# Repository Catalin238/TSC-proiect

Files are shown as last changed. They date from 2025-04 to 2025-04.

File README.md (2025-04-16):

# TSC-proiect

1. Diagrama Bloc



2. Bill of materials

| Piece Name | Quantity | Link |
|---|---|---|
| ESP32 | 1 | https://www.snapeda.com/parts/ESP32-C6-WROOM-1-N8/Espressif%20Systems/view-part/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 |
| BME680 | 1 | https://www.snapeda.com/parts/BME680/Bosch%20Sensortec/view-part/?ref=search&t=bme680 |
| DS3231SN | 1 | https://www.snapeda.com/parts/DS3231SN%23/Analog%20Devices/view-part/?ref=search&t=DS3231SN%23 |
| W25Q512JVEIQ | 1 | https://www.snapeda.com/parts/W25Q512JVEIQ/Winbond%20Electronics/view-part/?ref=search&t=W25Q512JVEIQ |
| MCP73831 | 1 | https://componentsearchengine.com/part-view/MCP73831T-2ACI%2FOT/Microchip |
| MOSFET | 1 | https://componentsearchengine.com/part-view/DMG2305UX-7/Diodes%20Incorporated |
| SAMACSYS_PARTS_USB4110-GF-A | 1 | https://www.snapeda.com/parts/USB4110-GF-A./Global%20Connector%20Technology/view-part/ |
| USBLC6-2SC6Y | 1 | https://www.snapeda.com/parts/USBLC6-2SC6Y/STMicroelectronics/view-part/?ref=dk&t=USBLC6-2SC6Y&con_ref=None |
| BD5229G-TR | 1 | https://www.snapeda.com/parts/BD5229G-TR/Rohm/view-part/?ref=search&t=BD5229G-TR |
| QWIIC_CONNECTOR | 1 | https://www.snapeda.com/parts/PRT-14417/SparkFun/view-part/ |
| CPH3225A | 1 | https://www.snapeda.com/parts/CPH3225A/Seiko/view-part/ |
| BUTTON_CUSYOMV1 | 3 | https://www.snapeda.com/search/?q=EVQP7L01P&search-type=parts |
| ADAFRUIT_LEDCHIP-LED0603 | 1 | https://www.snapeda.com/parts/KP-1608SURCK/Kingbright/view-part/?ref=search&t=LED%200603 |
| C0402 | 1 | https://componentsearchengine.com/part-view/CC0402MRX5R5BB106/YAGEO |
| 112ATAARR03 | 1 | https://www.snapeda.com/parts/112A-TAAR-R03/Attend/view-part/ |
| 744043680 | 1 | https://eu.mouser.com/ProductDetail/Wurth-Elektronik/744043680?qs=PGXP4M47uW6VkZq%252BkzjrHA%3D%3D |
| R0402 | 1 | https://componentsearchengine.com/part-view/R0402%201%25%20100%20K%20(RC0402FR-07100KL)/YAGEO |
| SD0805S020S1R0 | 1 | https://componentsearchengine.com/part-view/SD0805S020S1R0/Kyocera%20AVX |
| VARISTOR | 1 | https://ro.mouser.com/ProductDetail/EPCOS-TDK/B72520T0350K062?qs=dEfas%2FXlABIszF52uu7vrg%3D%3D |
| SRJ | 1 | https://componentsearchengine.com/part-view/FH34SRJ-24S-0.5SH(99)/Hirose |
| MBR0530 | 1 | https://www.snapeda.com/parts/MBR0530/Onsemi/view-part/ |
| PGB1010603MR | 1 | https://www.snapeda.com/parts/PGB1010603MR/Littelfuse/view-part/ |
| RCL_CPOL-EU | 1 | https://grabcad.com/library/tantalum-smd-capacitor-type-b-3528-1 |
| SI1308EDL-T1-GE3 | 1 | https://www.snapeda.com/parts/SI1308EDL-T1-GE3/Vishay/view-part/ |
| XC6220A331MR-G | 1 | https://ro.mouser.com/ProductDetail/Torex-Semiconductor/XC6220A331MR-G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 |

3. Functionalitati Hardware

Structura si Functionalitati:

ESP32-C6-WROOM-1-N8
Functie: Procesor central al sistemului, gestioneaza protocoalele de comunicare (SPI, I2C, UART), achizitia datelor de la senzori si controlul dispozitivelor periferice.

Connector USB-C cu Protectie ESD
Functie: Ofera posibilitatea incarcarii prin port USB-C si implementeaza circuite de protectie impotriva descarcarilor electrostatice.

Controller de Incarcare (MCP73831)
Functie: Administreaza procesul de incarcare pentru acumulatorul Li-Po si regleaza parametrii curentului de incarcare.

Acumulator Li-Po
Functie: Furnizeaza energie autonoma, permitand functionarea dispozitivului independent de conexiunea USB.

Regulator de Tensiune LDO
Functie: Converteste si mentine o tensiune stabila de 3.3V pentru alimentarea microcontrolerului si a componentelor auxiliare.

Memorie Flash NOR Externa 64MB
Functie: Asigura spatiu de stocare aditional pentru date operationale si actualizari de firmware.

Modul RTC (DS3231SN)
Functie: Asigura cronometrarea precisa si mentinerea datei/orei curente.
Conectivitate: Protocol I2C, include functii de alarma si baterie de rezerva pentru mentinerea timpului.

Senzor de Mediu (BME688)
Functie: Colecteaza parametri ambientali precum temperatura, umiditatea, presiunea atmosferica si compusi organici volatili.
Conectivitate: Comunicare I2C, optimizat pentru consum redus in standby, cu capacitati avansate de detectare a gazelor.
Implementare: Utilizeaza interfata standardizata Qwiic / Stemma QT pentru conectare plug-and-play.

Circuit de Control pentru Afisaj E-Paper si Conector
Functie: Produce semnalele specifice pentru operarea afisajelor electroforetice si faciliteaza compatibilitatea cu diferite tipuri de ecrane.
Conectivitate: Protocol SPI, cu linii dedicate pentru control (Busy, Reset, DC, CS).

Card SD
Functie: Faciliteaza stocarea extinsa a datelor, fisierelor de configurare si inregistrarilor pe termen lung.
Conectivitate: Interfata SPI cu linie dedicata de selectie.

Supervisor de Tensiune si Butoane Reset/Boot
Functie: Supravegheaza nivelul tensiunii de alimentare si controleaza secventele de initializare si repornire ale ESP32-C6.

Interfete si Protocoale de Comunicare:

I2C: Implementat pentru comunicarea cu BME688 si DS3231SN.
SPI: Utilizat pentru accesarea memoriei Flash NOR, controlul afisajului E-Paper si operatiunile cu cardul SD.
UART: Disponibil pentru debugging si integrarea modulelor externe optionale.
Wi-Fi si Bluetooth LE: Functionalitati native ale ESP32-C6.

Analiza Consumului Energetic:

ESP32-C6:
Consum in regim activ: ~80-240 mA (variabil in functie de activitatea Wi-Fi/BT).
Consum in regim economic: sub 1 mA (in modul deep sleep).

BME688:
Consum caracteristic: ~2.1 µA in repaus, maxim ~3.1 mA in operare completa.

Memorie Flash NOR:
Consum la citire/scriere: 5-15 mA, in asteptare: sub 10 µA.

DS3231SN:
Consum constant: aproximativ 150 µA cu functia de backup activa.

Regulator LDO:
Randamentul energetic variaza in functie de diferenta dintre tensiunea de intrare si cea de iesire (3.3V) si de curentul total solicitat.

4. Pini ESP32-C6

| Pin ESP32-C6  | Componenta / Rol | Descriere |
|---|---|---|
| IO8 (SCK) | SPI Clock | Semnal de clock SPI |
| IO6 (MOSI) | SPI MOSI catre NOR Flash, E-Paper, SD Card | Transfer date catre periferice SPI |
| IO7 (MISO) | SPI MISO din NOR Flash, E-Paper, SD Card | Receptie date de la periferice SPI |
| IO9 (CS1) | Chip Select NOR Flash | Control dedicat pentru NOR Flash |
| IO11 (CS3) | Chip Select SD Card | Control dedicat pentru SD Card |
| IO10 (CS2) | Chip Select E-Paper Display | Control dedicat pentru Display |
| IO15 (SCL) | I2C SCL catre BME688 si DS3231SN | Semnal de clock I2C |
| IO14 (SDA) | I2C SDA catre BME688 si DS3231SN | Date pentru I2C |
| IO21 | Reset/Boot control | Butoane de reset si boot |
| IO16, IO17 | UART RX, TX (debug) | Debug serial si configurare |

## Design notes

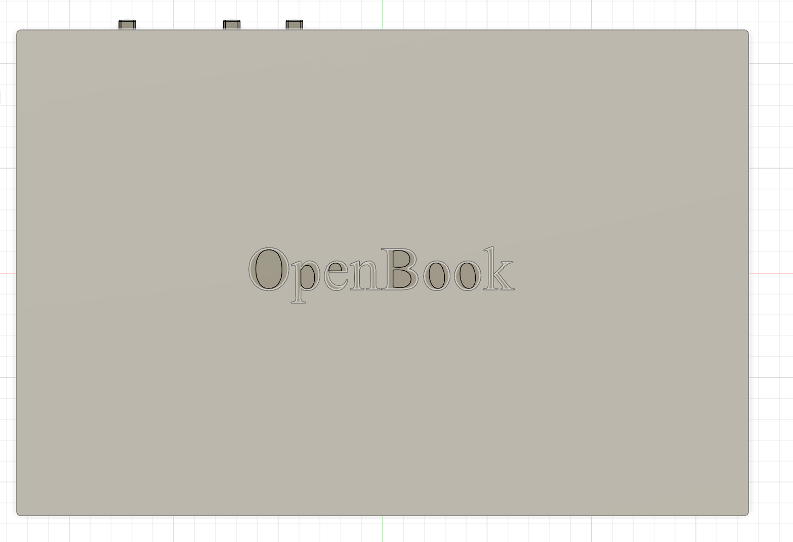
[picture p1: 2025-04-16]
Images/OpenBook Enclosure.png

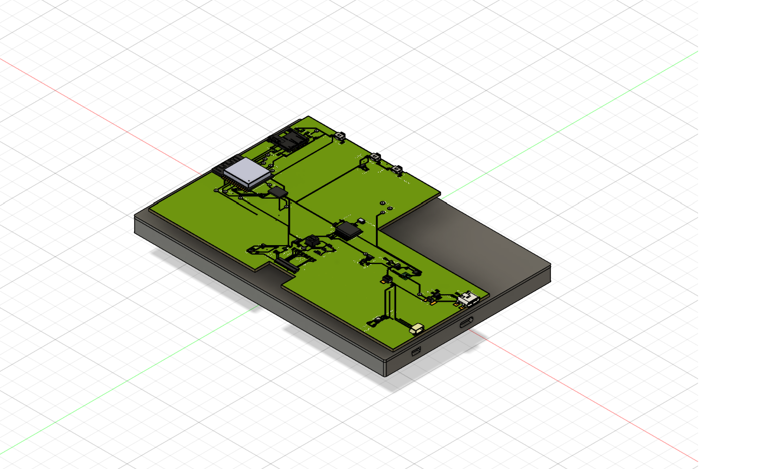
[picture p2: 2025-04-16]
Images/OpenBook.png

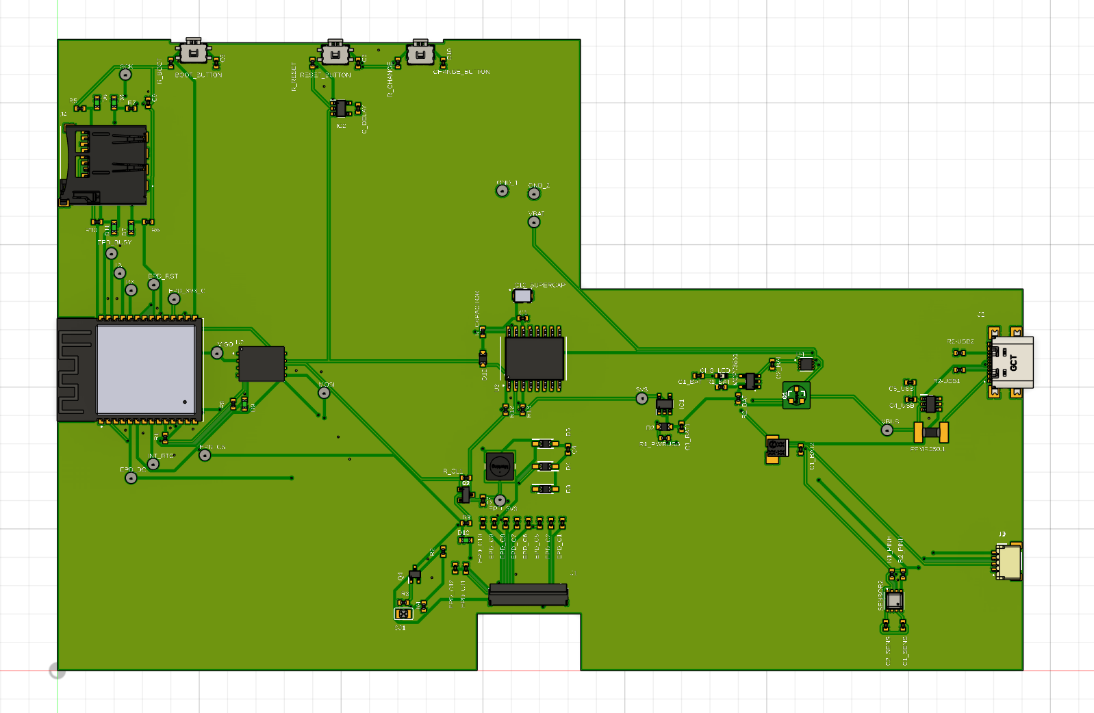
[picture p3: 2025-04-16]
Images/3d_board.png

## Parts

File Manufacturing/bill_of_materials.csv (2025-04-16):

Qty | Value | Device | Package | Parts | Description | ARROW_PART_NUMBER | ARROW_PRICE-STOCK | AVAILABILITY | BOOT_BUTTON | CENTROID_NOT_SPECIFIED | CHANGE_BUTTON | CHECK_PRICES | COPYRIGHT | DATASHEET | DESCRIPTION | DIGIKEY_DESCRIPTION | DIGIKEY_PART_NUMBER | DMG2305UX-7 | HEIGHT | LEAD_FREE | MANUFACTURER_NAME | MANUFACTURER_PART_NUMBER | MF | MFR_NAME | MOUSER_PART_NUMBER | MOUSER_PRICE-STOCK | MOUSER_TESTING_PART_NUMBER | MOUSER_TESTING_PRICE-STOCK | MP | MPN | PACKAGE | POPULARITY | PREFIX | PRICE | PROD_ID | PURCHASE-URL | RESET_BUTTON | ROHS | SNAPEDA_LINK | SPICEPREFIX | TEMPERATURE_RANGE_HIGH | TEMPERATURE_RANGE_LOW | VALUE
1 |  | SJ | SJ | SJ1 | SMD solder JUMPER |  |  |  |  |  |  |  |  |  |  |  |  |  |  |  |  |  |  |  |  |  |  |  |  |  |  | 3
1 | 0.1uF/50V | EAGLE-LTSPICE_C | EAGLE-LTSPICE_C0402 | EPD_C5 | CAPACITOR, European symbol
1 | 0.47 | ESP32_WROVER_EAGLE-LTSPICE_R | ESP32_WROVER_EAGLE-LTSPICE_R0402 | R2 | RESISTOR, European symbol
1 | 100K | ESP32_WROVER_EAGLE-LTSPICE_R | ESP32_WROVER_EAGLE-LTSPICE_R0402 | R1_PWRUSB | RESISTOR, European symbol
8 | 100nF | EAGLE-LTSPICE_C | EAGLE-LTSPICE_C0402 | C1, C1_SENS, C2_SENS, C4_USB, C6, C9, C10, C_DELAY | CAPACITOR, European symbol
1 | 100uF TANT | RCL_CPOL-EUCT3528 | RCL_CT3528 | C3 | POLARIZED CAPACITOR, European symbol |  |  |  |  |  |  |  |  |  |  |  |  |  |  |  |  |  |  |  |  |  |  |  |  |  |  | 0 |  |  |  |  |  |  |  | C
16 | 10K | ESP32_WROVER_EAGLE-LTSPICE_R | ESP32_WROVER_EAGLE-LTSPICE_R0402 | R1, R1_PINH, R2_PINH, R3, R5, R6, R7, R8, R9, R10, R12, R13, R_BOOT, R_CHANGE, R_CL1, R_RESET | RESISTOR, European symbol
1 | 10uF | EAGLE-LTSPICE_C | EAGLE-LTSPICE_C0402 | C7 | CAPACITOR, European symbol
1 | 112A-TAAR-R03_ATTEND | 112A-TAAR-R03_ATTEND | 112ATAARR03ATTEND | J4 | Micro SD Card Socket, Push-Push Type, Top Mount, SMT, H=1.83mm, 10u |  |  |  |  |  |  |  |  |  | Micro SD Card Socket | Push-Push Type | Top Mount | SMT | H=1.83mm | 10u |  |  |  | 1.9mm |  | ATTEND | 112A-TAAR-R03 ATTEND
1 | 15 | ESP32_WROVER_EAGLE-LTSPICE_R | ESP32_WROVER_EAGLE-LTSPICE_R0402 | R_CAPACITOR | RESISTOR, European symbol
1 | 1uF | EAGLE-LTSPICE_C | EAGLE-LTSPICE_C0402 | C5 | CAPACITOR, European symbol
9 | 1uF/50V | EAGLE-LTSPICE_C | EAGLE-LTSPICE_C0402 | EPD_C1, EPD_C2, EPD_C6, EPD_C7, EPD_C8, EPD_C9, EPD_C10, EPD_C11, EPD_C12 | CAPACITOR, European symbol
1 | 2.2 | ESP32_WROVER_EAGLE-LTSPICE_R | ESP32_WROVER_EAGLE-LTSPICE_R0402 | R4 | RESISTOR, European symbol
1 | 200 | ESP32_WROVER_EAGLE-LTSPICE_R | ESP32_WROVER_EAGLE-LTSPICE_R0402 | R1_BAT | RESISTOR, European symbol
2 | 20V/4.2A/52mO/1.4W | ESP32_WROVER_SPARKFUN-DISCRETESEMI_MOSFET_PCH | ESP32_WROVER_SPARKFUN-DISCRETESEMI_SOT23-3 | Q1, Q2 | P-channel MOSFETs
1 | 2K | ESP32_WROVER_EAGLE-LTSPICE_R | ESP32_WROVER_EAGLE-LTSPICE_R0402 | R2_BAT | RESISTOR, European symbol
5 | 4.7uF | EAGLE-LTSPICE_C | EAGLE-LTSPICE_C0402 | C1_BAT, C1_BAT1, C1_BAT2, C2_BAT, C5_USB | CAPACITOR, European symbol
1 | 4.7uF/25V | EAGLE-LTSPICE_C | EAGLE-LTSPICE_C0402 | C4 | CAPACITOR, European symbol
2 | 5k1 | ESP32_WROVER_EAGLE-LTSPICE_R | ESP32_WROVER_EAGLE-LTSPICE_R0402 | R2-USB1, R2-USB2 | RESISTOR, European symbol
1 | 68uH | 744043680IND_4828-WE-TPC_WRE | IND_4828-WE-TPC_WRE | L1 |  |  |  |  |  |  |  |  | Copyright (C) 2024 Ultra Librarian. All rights reserved. |  |  |  |  |  |  |  |  | 744043680 |  | Wurth Electronics
1 | BD5229G-TR | BD5229G-TR | SOT95P280X125-5N | IC2 | Voltage Detector with Adjustable Delay Time: CMOS processes are utilized to develop high precision, low current consumption CMOS reset ICs that allow arbitrary setting of the delay time. The extensive lineup includes both Nch Open Drain and CMOS output types in a wide range of detection voltages (from 2.3V to 6.0V, in 0.1V steps), enabling selection of the ideal solution based on customer requirements. In addition, the entire series is of course both lead-free and RoHS-compliant. |  |  |  |  |  |  |  |  |  | Voltage Detector with Adjustable Delay Time: CMOS processes are utilized to develop high precision | low current consumption CMOS reset ICs that allow arbitrary setting of the delay time. The extensive lineup includes both Nch Open Drain and CMOS output types in a wide range of detection voltages (from 2.3V to 6.0V | in 0.1V steps) | enabling selection of the ideal solution based on customer requirements. In addition | the entire series is of course both lead-free and RoHS-compliant. |  |  |  | 1.25mm |  | ROHM Semiconductor | BD5229G-TR |  |  | 755-BD5229G-TR | https://www.mouser.co.uk/ProductDetail/ROHM-Semiconductor/BD5229G-TR?qs=4kLU8WoGk0vvnhrrYwdszw%3D%3D
1 | BME688 | ESP32_WROVER_BME680_BME680 | ESP32_WROVER_BME680_PSON80P300X300X100-8N | SENSOR2 | Integrated Environmental Unit |  |  | Unavailable |  |  |  |  |  |  | Integrated Environmental Unit |  |  |  |  |  |  |  | Bosch Sensortec |  |  |  |  |  | BME680 |  | LGA-8 Bosch Tools |  |  | None
3 | BUTTON_CUSYOMV1 | BUTTON_CUSYOMV1 | MYBUTTON | BOOT_BUTTON, CHANGE_BUTTON, RESET_BUTTON
1 | CPH3225A | CPH3225A | CAPCP3225X100N | C10_SUPERCAP | Cap 0.011F 3.3V 1210 Flat Check availability |  |  | Not in stock |  |  |  | https://www.snapeda.com/parts/CPH3225A/Seiko+Instruments/view-part/?ref=eda |  |  | 11 mF (EDLC) Supercapacitor 3.3 V 1210 (3225 Metric) - - |  |  |  |  |  |  |  | Seiko Instruments |  |  |  |  |  | CPH3225A |  | 1210 Seiko |  |  | None |  | https://www.snapeda.com/api/url_track_click_mouser/?unipart_id=562593&manufacturer=Seiko Instruments&part_name=CPH3225A&search_term=None |  |  | https://www.snapeda.com/parts/CPH3225A/Seiko+Instruments/view-part/?ref=snap
1 | DS3231SN# | DS3231SN# | SOIC127P1032X265-16N | U3 | Real Time Clock Serial 16-Pin SOIC W T/R Check availability |  |  | In Stock |  |  |  | https://www.snapeda.com/parts/DS3231SN%23/Analog+Devices/view-part/?ref=eda |  |  | Extremely Accurate I²C-Integrated RTC/TCXO/Crystal |  |  |  |  |  |  |  | Analog Devices |  |  |  |  |  | DS3231SN# |  | SOIC-16 Maxim |  |  | None |  | https://www.snapeda.com/api/url_track_click_mouser/?unipart_id=99048&manufacturer=Analog Devices&part_name=DS3231SN#&search_term=None |  |  | https://www.snapeda.com/parts/DS3231SN%23/Analog+Devices/view-part/?ref=snap
1 | ESP32-C6-WROOM-1-N8 | ESP32-C6-WROOM-1-N8 | XCVR_ESP32-C6-WROOM-1-N8 | U1 | Check availability |  |  | In Stock |  |  |  | https://www.snapeda.com/parts/ESP32-C6-WROOM-1-N8/Espressif+Systems/view-part/?ref=eda |  |  | Multiprotocol Modules ESP32-C6 module | Wi-Fi 6 in 2.4 GHz band | Bluetooth 5 | Zigbee 3.0 and Thread. ESP34-WROOM Compatible - ENGINEERING SAMPLE |  |  |  |  |  |  |  | Espressif Systems |  |  |  |  |  | ESP32-C6-WROOM-1-N8 |  | None |  |  | None |  |  |  |  | https://www.snapeda.com/parts/ESP32-C6-WROOM-1-N8/Espressif+Systems/view-part/?ref=snap
1 | ESP32C6_VARISTORCN1812 | ESP32C6_VARISTORCN1812 | ESP32C6_VARISTOR_CT/CN1812 | PFMF.050.1 | VARISTOR |  |  |  |  |  |  |  |  |  |  |  |  |  |  |  |  |  |  |  |  |  |  |  |  |  |  | 0
2 | ESP32_WROVER_AVX---SD0805S020S1R0_AVX_SD0805S020S1R0_0_0AVX_SD0805S020S1R0_0_0 | ESP32_WROVER_AVX---SD0805S020S1R0_AVX_SD0805S020S1R0_0_0AVX_SD0805S020S1R0_0_0 | ESP32_WROVER_AVX---SD0805S020S1R0_AVX_SD0805S020S1R0_0 | D2, D12 | Schottky Barrier Rectifier Diode |  |  |  |  | No |  |  |  | http://datasheets.avx.com/schottky.pdf |  | DIODE SCHOTTKY 20V 1A 0805 | 478-7800-1-ND |  |  | yes |  |  | AVX |  | 581-SD0805S020S1R0 |  |  |  |  |  | 0805 (2012 metric) |  | D |  |  |  |  | yes |  |  | +125°C | -55°C
1 | ESP32_WROVER_SPARKFUN-IC-POWER_MCP73831 | ESP32_WROVER_SPARKFUN-IC-POWER_MCP73831 | ESP32_WROVER_SPARKFUN-IC-POWER_SOT23-5 | MCP73831 | MCP73831T Li-Ion, Li-Pol Controller |  |  |  |  |  |  |  |  |  |  |  |  |  |  |  |  |  |  |  |  |  |  |  |  |  |  |  |  |  | IC-09995
1 | FH34SRJ-24S-0.5SH_99_ | FH34SRJ-24S-0.5SH_99_ | FH34SRJ24S05SH99 | J1 | (0.50mm) Surface Mount, Right Angle |  |  |  |  |  |  |  |  |  | 24 Position FFC | FPC Connector Contacts | (0.50mm) Surface Mount | Right Angle |  |  |  | 1.1mm |  | Hirose | FH34SRJ-24S-0.5SH(99) |  |  | 798-FH34SRJ24S05SH99 | https://www.mouser.co.uk/ProductDetail/Hirose-Connector/FH34SRJ-24S-0.5SH99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
1 | LG R971 | ADAFRUIT_LEDCHIP-LED0603 | ADAFRUIT_CHIP-LED0603 | CHG_LED | LED
1 | MAX17048G+T10 | MAX17048G+T10 | SON50P200X200X80-9N | U4 | Check availability |  |  | In Stock |  |  |  | https://www.snapeda.com/parts/MAX17048G+T10/Analog+Devices/view-part/?ref=eda |  |  | 3µA 1-Cell/2-Cell Fuel Gauge with ModelGauge |  |  |  |  |  |  |  | Analog Devices |  |  |  |  |  | MAX17048G+T10 |  | TDFN-8 Maxim |  |  | None |  | https://www.snapeda.com/api/url_track_click_mouser/?unipart_id=329239&manufacturer=Analog Devices&part_name=MAX17048G+T10&search_term=None |  |  | https://www.snapeda.com/parts/MAX17048G+T10/Analog+Devices/view-part/?ref=snap
3 | MBR0530CEVA | MBR0530CEVA | SOD3716X135N | D3, D4, D5 | ON SEMICONDUCTOR - MBR0530 - DIODE, SCHOTTKY, 0.5A, 30V, SOD-123
6 | PGB1010603MRCEVA2 | PGB1010603MRCEVA2 | DIOC1608X36N | D6, D7, D8, D9, D10, D11 | Check availability
1 | QWIIC_RIGHT_ANGLE | QWIIC_CONNECTORJS-1MM | JST04_1MM_RA | J3 | SparkFun I2C Standard Qwiic Connector |  |  |  |  |  |  |  |  |  |  |  |  |  |  |  |  |  |  |  |  |  |  |  |  |  |  |  |  |  | CONN-13694 |  |  |  |  |  |  |  | QWIIC_RIGHT_ANGLE
1 | SAMACSYS_PARTS_USB4110-GF-A | SAMACSYS_PARTS_USB4110-GF-A | SAMACSYS_PARTS_USB4110GFA | J2 | CONN USB 2.0 TYPE-C R/A SMT |  |  |  |  |  |  |  |  |  | CONN USB 2.0 TYPE-C R/A SMT |  |  |  | 3.26mm |  | GCT (GLOBAL CONNECTOR TECHNOLOGY) | USB4110-GF-A |  |  | 640-USB4110-GF-A | https://www.mouser.co.uk/ProductDetail/GCT/USB4110-GF-A?qs=KUoIvG%2F9IlYiZvIXQjyJeA%3D%3D
1 | SI1308EDL-T1-GE3 | SI1308EDL-T1-GE3 | SOT65P210X110-3N | Q4 | MOSFET N-Ch 30V 1.5A TrenchFET SC70 Vishay Si1308EDL-T1-GE3 N-channel MOSFET Transistor, 1.5 A, 30 V, 3-Pin SC-70 |  |  | In Stock |  |  |  | https://www.snapeda.com/parts/SI1308EDL-T1-GE3/Vishay+Siliconix/view-part/?ref=eda |  |  | Si1308EDL-T1-GE3 N-channel MOSFET Transistor | 1.5 A | 30 V | 3-Pin SC-70 | Siliconix / Vishay SI1308EDL-T1-GE3 |  |  |  |  |  |  |  | Vishay Siliconix |  |  |  |  |  | SI1308EDL-T1-GE3 |  | SOT-323 Vishay Semiconductor |  |  | None |  | https://www.snapeda.com/api/url_track_click_mouser/?unipart_id=274603&manufacturer=Vishay Siliconix&part_name=SI1308EDL-T1-GE3&search_term=None |  |  | https://www.snapeda.com/parts/SI1308EDL-T1-GE3/Vishay+Siliconix/view-part/?ref=snap
17 | TP | TP | TP20R | 3V3, EPD_3V3, EPD_3V3_C, EPD_BUSY, EPD_CS, EPD_DC, EPD_RST, GND_1, GND_2, INT_RTC, MISO, MOSI, RX, SCK, TX, VBAT, VBUS | Test pad
1 | USBLC6-2SC6Y | USBLC6-2SC6Y | SOT95P280X145-6N | D1 | Low Cap. ESD Protection Auto SOT-23-6 STMicroelectronics USBLC6-2SC6Y, Dual Uni-Directional TVS Diode Array, 6-Pin SOT-23 |  |  | In Stock |  |  |  | https://www.snapeda.com/parts/USBLC6-2SC6Y/STMicroelectronics/view-part/?ref=eda |  |  | 17V Clamp 5A (8/20µs) Ipp Tvs Diode Surface Mount SOT-23-6 |  |  |  |  |  |  |  | STMicroelectronics |  |  |  |  |  | USBLC6-2SC6Y |  | SOT-23-6 STMicroelectronics |  |  | None |  |  |  |  | https://www.snapeda.com/parts/USBLC6-2SC6Y/STMicroelectronics/view-part/?ref=snap
1 | W25Q512JVEIQ | W25Q512JVEIQ | SON127P600X800X80-9N | U2 | Check availability |  |  | In Stock |  |  |  | https://www.snapeda.com/parts/W25Q512JVEIQ/Winbond+Electronics/view-part/?ref=eda |  |  | FLASH - NOR Memory IC 512Mb (64M x 8) SPI - Quad I/O 133 MHz 8-WSON (8x6) |  |  |  |  |  |  |  | Winbond Electronics |  |  |  |  |  | W25Q512JVEIQ |  | Package |  |  | None |  |  |  |  | https://www.snapeda.com/parts/W25Q512JVEIQ/Winbond+Electronics/view-part/?ref=snap
1 | XC6220A331MR-G | XC6220A331MR-G | SOT95P280X120-5N | IC1 | LDO Voltage Regulators |  |  |  |  |  |  |  |  |  | LDO Voltage Regulators |  |  |  | 1.2mm |  | Torex | XC6220A331MR-G |  |  | 865-XC6220A331MR-G | https://www.mouser.co.uk/ProductDetail/Torex-Semiconductor/XC6220A331MR-G?qs=AsjdqWjXhJ8ZSWznL1J0gg%3D%3D

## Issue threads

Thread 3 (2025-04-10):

Missing documentation

mateiplescan, 2025-04-10:
Missing documentation. Consider writing documentation for the project.

Documentation should include:

- bill of materials (include links to datasheet and supplier)
- list of main components and how they are linked to the microcontroller
- description of main components
- description of pin usage for each pin of the microcontroller
- block diagram

For reference, use https://ocw.cs.pub.ro/courses/tsc/proiect2025

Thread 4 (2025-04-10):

Copper width

mateiplescan, 2025-04-10:
Signal wires have a 0.127 mm width. According to the manufacturer's technical limitations, the minimum width of copper wires on the PCB should be 0.15mm. Please refer to the official announcement: https://teams.microsoft.com/l/message/19:de41UIg-Kw9l2gSJREYXzCUl0TyWzT9KYZOCbGyNKgA1@thread.tacv2/1742933371887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

Consider modifying the width of all signal wires, and check if other errors which might occur (around vias or pins).

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

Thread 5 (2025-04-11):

GND Pour

mateiplescan, 2025-04-11:
On the top and bottom layers, there are some copper pour islands, due to wires isolating them.

Consider using via stitching to connect the islands with the pour.

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

Closed 2025-04-16.

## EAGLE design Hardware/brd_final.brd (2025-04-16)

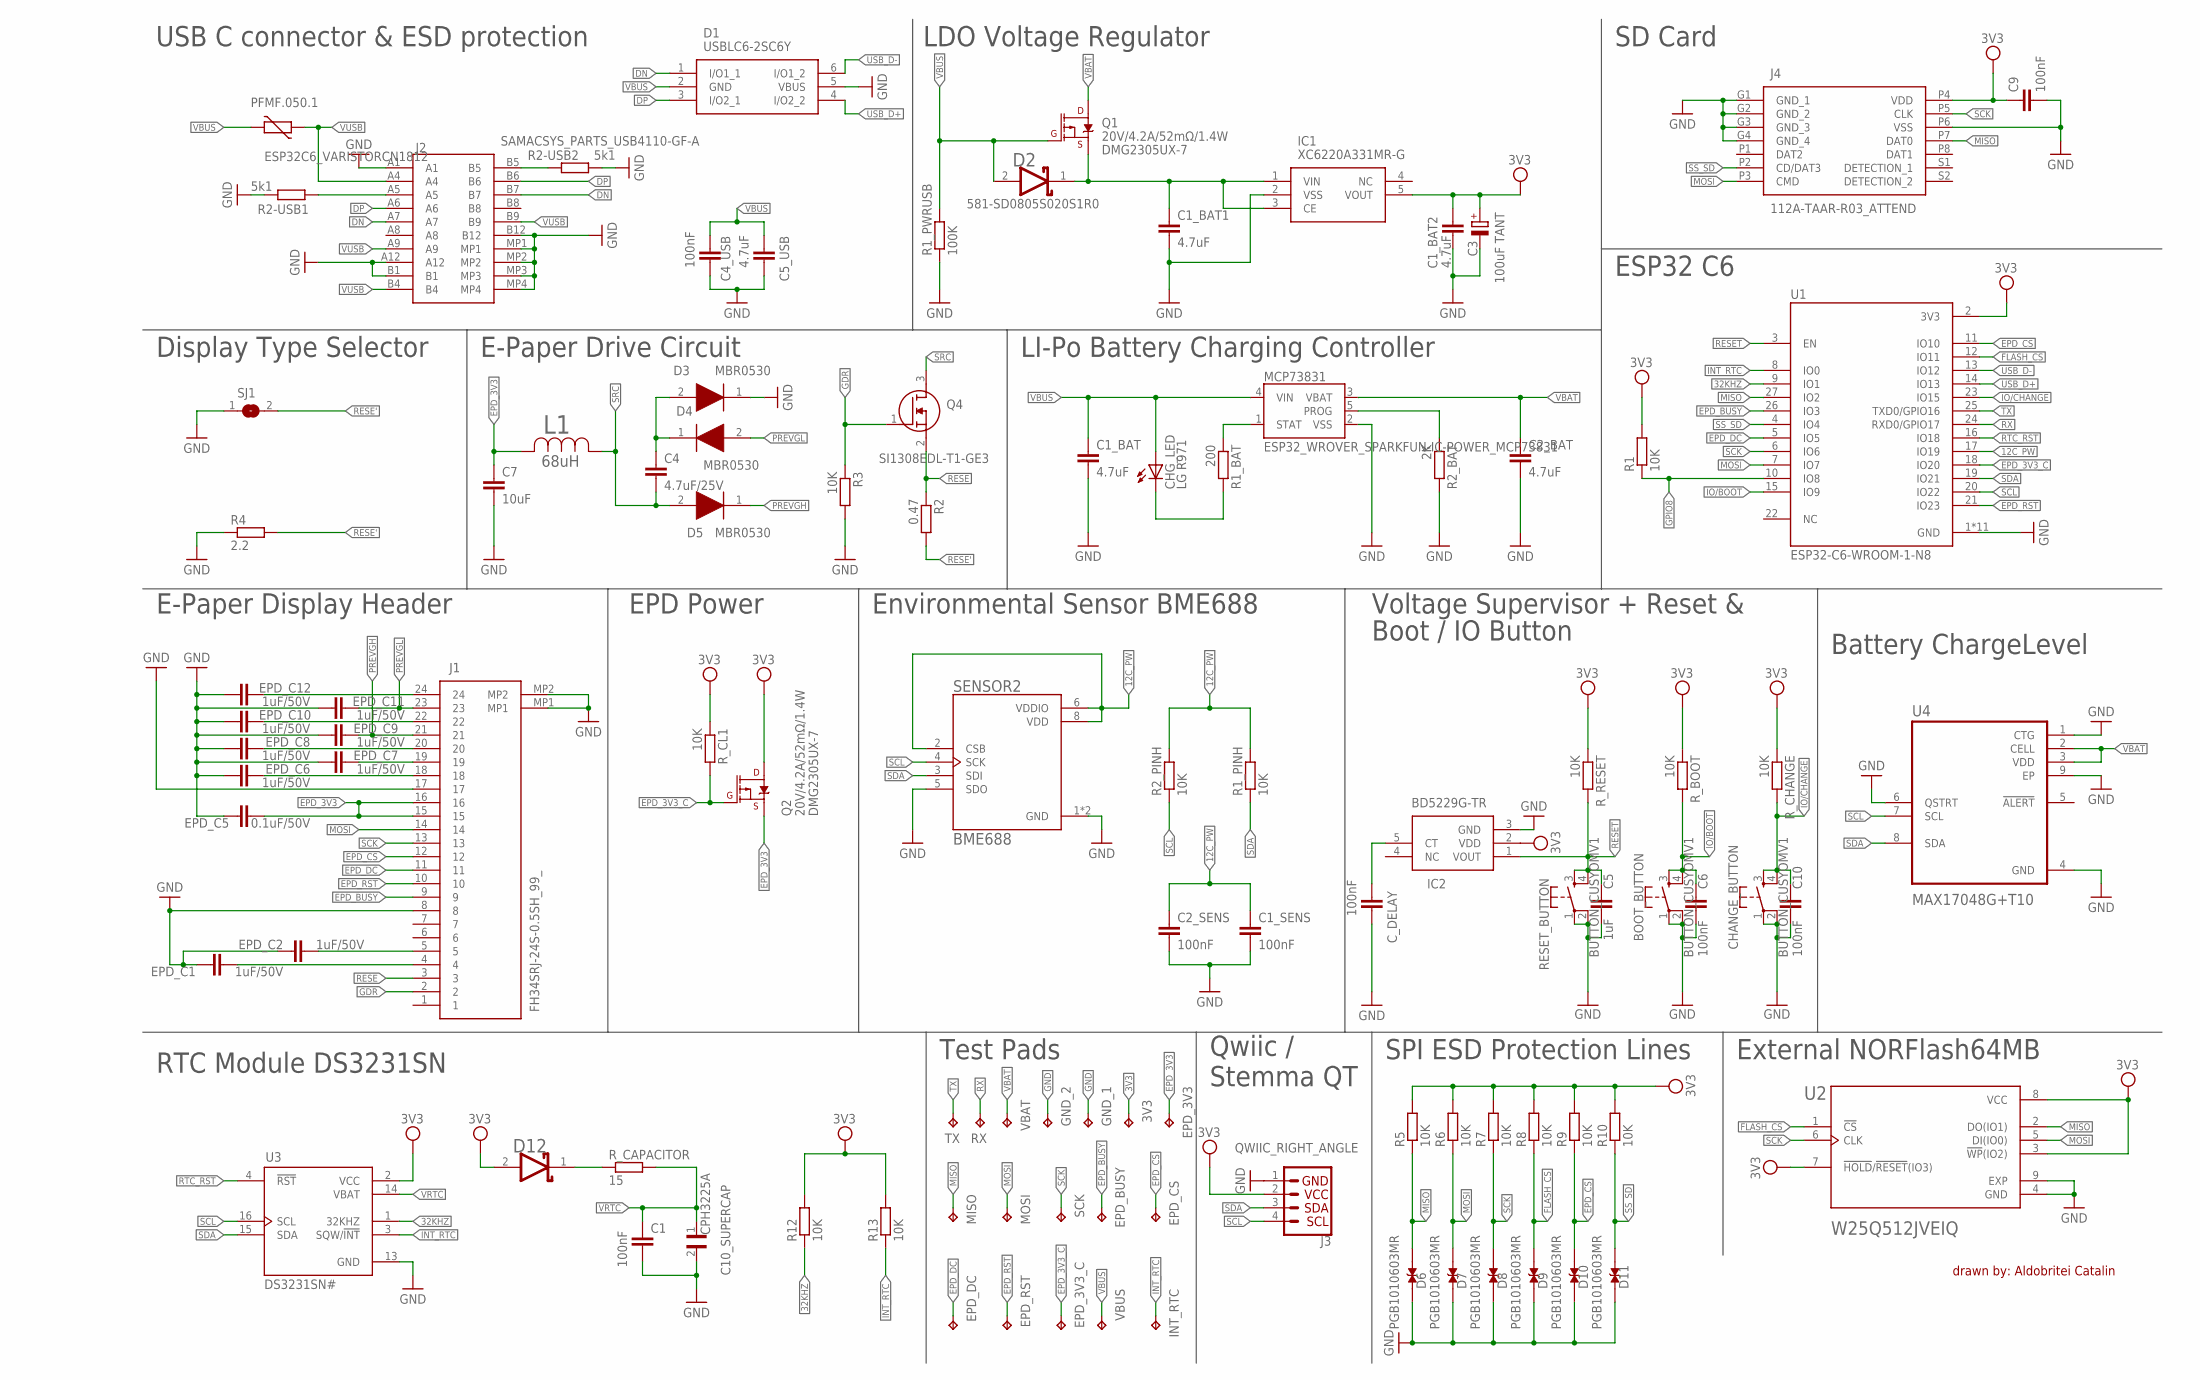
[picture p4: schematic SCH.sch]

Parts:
3V3: TPTP20R; TP20R
BOOT_BUTTON: BUTTON_CUSYOMV1; MYBUTTON
C1, C1_SENS, C2_SENS, C4_USB, C6, C9, C10: 100nF; EAGLE-LTSPICE_C0402
C1_BAT, C1_BAT1, C1_BAT2, C2_BAT, C5_USB: 4.7uF; EAGLE-LTSPICE_C0402
C3: 100uF TANT; RCL_CT3528
C4: 4.7uF/25V; EAGLE-LTSPICE_C0402
C5: 1uF; EAGLE-LTSPICE_C0402
C7: 10uF; EAGLE-LTSPICE_C0402
C10_SUPERCAP: CPH3225A; CAPCP3225X100N
CHANGE_BUTTON: BUTTON_CUSYOMV1; MYBUTTON
CHG_LED: LG R971; ADAFRUIT_CHIP-LED0603
C_DELAY: 100nF; EAGLE-LTSPICE_C0402
D1: USBLC6-2SC6Y; SOT95P280X145-6N
D2, D12: ESP32_WROVER_AVX---SD0805S020S1R0_AVX_SD0805S020S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; ESP32_WROVER_AVX---SD0805S020S1R0_AVX_SD0805S020S1R0_0
D3, D4, D5: MBR0530; SOD3716X135N
D6, D7, D8, D9, D10, D11: PGB1010603MR; DIOC1608X36N
EPD_3V3, EPD_3V3_C: TPTP20R; TP20R
EPD_BUSY: TPTP20R; TP20R
EPD_C1, EPD_C2, EPD_C6, EPD_C7, EPD_C8, EPD_C9, EPD_C10, EPD_C11, EPD_C12: 1uF/50V; EAGLE-LTSPICE_C0402
EPD_C5: 0.1uF/50V; EAGLE-LTSPICE_C0402
EPD_CS: TPTP20R; TP20R
EPD_DC: TPTP20R; TP20R
EPD_RST: TPTP20R; TP20R
GND_1, GND_2: TPTP20R; TP20R
IC1: XC6220A331MR-G; SOT95P280X120-5N
IC2: BD5229G-TR; SOT95P280X125-5N
INT_RTC: TPTP20R; TP20R
J1: FH34SRJ-24S-0.5SH_99_; FH34SRJ24S05SH99
J2: SAMACSYS_PARTS_USB4110-GF-A; SAMACSYS_PARTS_USB4110GFA
J3: QWIIC_RIGHT_ANGLE; JST04_1MM_RA
J4: 112A-TAAR-R03_ATTEND; 112ATAARR03ATTEND
L1: 68uH; IND_4828-WE-TPC_WRE
MCP73831: ESP32_WROVER_SPARKFUN-IC-POWER_MCP73831; ESP32_WROVER_SPARKFUN-IC-POWER_SOT23-5
MISO: TPTP20R; TP20R
MOSI: TPTP20R; TP20R
PFMF.050.1: ESP32C6_VARISTORCN1812; ESP32C6_VARISTOR_CT/CN1812
Q1, Q2: 20V/4.2A/52mΩ/1.4W; ESP32_WROVER_SPARKFUN-DISCRETESEMI_SOT23-3
Q4: SI1308EDL-T1-GE3; SOT65P210X110-3N
R1, R1_PINH, R2_PINH, R3, R5, R6, R7, R8, R9, R10, R12, R13: 10K; ESP32_WROVER_EAGLE-LTSPICE_R0402
R1_BAT: 200; ESP32_WROVER_EAGLE-LTSPICE_R0402
R1_PWRUSB: 100K; ESP32_WROVER_EAGLE-LTSPICE_R0402
R2: 0.47; ESP32_WROVER_EAGLE-LTSPICE_R0402
R2-USB1, R2-USB2: 5k1; ESP32_WROVER_EAGLE-LTSPICE_R0402
R2_BAT: 2K; ESP32_WROVER_EAGLE-LTSPICE_R0402
R4: 2.2; ESP32_WROVER_EAGLE-LTSPICE_R0402
RESET_BUTTON: BUTTON_CUSYOMV1; MYBUTTON
RX: TPTP20R; TP20R
R_BOOT: 10K; ESP32_WROVER_EAGLE-LTSPICE_R0402
R_CAPACITOR: 15; ESP32_WROVER_EAGLE-LTSPICE_R0402
R_CHANGE: 10K; ESP32_WROVER_EAGLE-LTSPICE_R0402
R_CL1: 10K; ESP32_WROVER_EAGLE-LTSPICE_R0402
R_RESET: 10K; ESP32_WROVER_EAGLE-LTSPICE_R0402
SCK: TPTP20R; TP20R
SENSOR2: BME688; ESP32_WROVER_BME680_PSON80P300X300X100-8N
SJ1: SJ
TX: TPTP20R; TP20R
U1: ESP32-C6-WROOM-1-N8; XCVR_ESP32-C6-WROOM-1-N8
U2: W25Q512JVEIQ; SON127P600X800X80-9N
U3: DS3231SN#; SOIC127P1032X265-16N
U4: MAX17048G+T10; SON50P200X200X80-9N
VBAT: TPTP20R; TP20R
VBUS: TPTP20R; TP20R

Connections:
3V3: 3V3.TP, C1_BAT2.2, C3.+, C9.1, D12.2 (ANODE), IC1.5 (VOUT), IC2.2 (VDD), J3.2, J4.P4 (VDD), Q2.3 (D), R1.2, R5.2, R6.2, R7.2, R8.2, R9.2, R10.2, R12.2, R13.2, R_BOOT.1, R_CHANGE.1, R_CL1.1, R_RESET.1, U1.2 (3V3), U2.3 (!WP!(IO2)), U2.7 (!HOLD!/!RESET!(IO3)), U2.8 (VCC), U3.2 (VCC)
32KHZ: R12.1, U1.9 (IO1), U3.1 (32KHZ)
DN: D1.1 (I/O1_1), J2.A7, J2.B7
DP: D1.3 (I/O2_1), J2.A6, J2.B6
EPD_3V3: C7.1, EPD_3V3.TP, EPD_C5.2, J1.15, J1.16, L1.2, Q2.2 (S)
EPD_3V3_C: EPD_3V3_C.TP, Q2.1 (G), R_CL1.2, U1.18 (IO20)
EPD_BUSY: EPD_BUSY.TP, J1.9, U1.26 (IO3)
EPD_CS: D10.2, EPD_CS.TP, J1.12, R9.1, U1.11 (IO10)
EPD_DC: EPD_DC.TP, J1.11, U1.5 (IO5)
EPD_RST: EPD_RST.TP, J1.10, U1.21 (IO23)
FLASH_CS: D9.2, R8.1, U1.12 (IO11), U2.1 (!CS)
GDR: J1.2, Q4.1 (G), R3.1
GND: BOOT_BUTTON.1, BOOT_BUTTON.2, C1.2, C1_BAT.2, C1_BAT1.2, C1_BAT2.1, C1_SENS.2, C2_BAT.2, C2_SENS.2, C3.-, C4_USB.2, C5.2, C5_USB.2, C6.2, C7.2, C9.2, C10.2, C10_SUPERCAP.2, CHANGE_BUTTON.1, CHANGE_BUTTON.2, C_DELAY.2, D1.5 (VBUS), D3.1 (K), D6.1, D7.1, D8.1, D9.1, D10.1, D11.1, EPD_C1.1, EPD_C2.1, EPD_C5.1, EPD_C6.1, EPD_C7.1, EPD_C8.1, EPD_C9.1, EPD_C10.1, EPD_C11.1, EPD_C12.1, GND_1.TP, GND_2.TP, IC1.2 (VSS), IC2.3 (GND), J1.8, J1.17, J1.MP1, J1.MP2, J2.A1, J2.A12, J2.B1, J2.B12, J2.MP1, J2.MP2, J2.MP3, J2.MP4, J3.1, J4.G1 (GND_1), J4.G2 (GND_2), J4.G3 (GND_3), J4.G4 (GND_4), J4.P6 (VSS), MCP73831.2 (VSS), R1_PWRUSB.1, R2-USB1.1, R2-USB2.2, R2_BAT.2, R3.2, R4.1, RESET_BUTTON.1, RESET_BUTTON.2, SENSOR2.1 (GND), SENSOR2.5 (SDO), SENSOR2.7 (GND), SJ1.1, U1.1 (GND), U1.28 (GND), U1.29_1 (GND), U1.29_2 (GND), U1.29_3 (GND), U1.29_4 (GND), U1.29_5 (GND), U1.29_6 (GND), U1.29_7 (GND), U1.29_8 (GND), U1.29_9 (GND), U2.4 (GND), U2.9 (EXP), U3.13 (GND), U4.1 (CTG), U4.4 (GND), U4.6 (QSTRT), U4.9 (EP)
GND1: J2.B5, R2-USB2.1
GPIO8: R1.1, U1.10 (IO8)
INT_RTC: INT_RTC.TP, R13.1, U1.8 (IO0), U3.3 (SQW/!INT)
IO/BOOT: BOOT_BUTTON.3, BOOT_BUTTON.4, C6.1, R_BOOT.2, U1.15 (IO9)
IO/CHANGE: C10.1, CHANGE_BUTTON.3, CHANGE_BUTTON.4, R_CHANGE.2, U1.23 (IO15)
MISO: D6.2, J4.P7 (DAT0), MISO.TP, R5.1, U1.27 (IO2), U2.2 (DO(IO1))
MOSI: D7.2, J1.14, J4.P3 (CMD), MOSI.TP, R6.1, U1.7 (IO7), U2.5 (DI(IO0))
unnamed: J2.A5, R2-USB1.2
unnamed: EPD_C7.2, J1.19
unnamed: MCP73831.1 (STAT), R1_BAT.1
unnamed: C1_BAT1.1, D2.1 (CATHODE), IC1.1 (VIN), IC1.3 (CE), Q1.2 (S)
unnamed: CHG_LED.C, R1_BAT.2
unnamed: EPD_C6.2, J1.18
unnamed: MCP73831.5 (PROG), R2_BAT.1
unnamed: C4.1, D3.2 (A), D4.1 (K)
unnamed: EPD_C8.2, J1.20
unnamed: EPD_C10.2, J1.22
unnamed: EPD_C12.2, J1.24
unnamed: C_DELAY.1, IC2.5 (CT)
unnamed: EPD_C2.2, J1.5
unnamed: EPD_C1.2, J1.4
unnamed: D12.1 (CATHODE), R_CAPACITOR.1
PREVGH: D5.1 (K), EPD_C9.2, J1.21
PREVGL: D4.2 (A), EPD_C11.2, J1.23
RESE: J1.3, Q4.2 (S), R2.1
RESE': R2.2, R4.2, SJ1.2
RESET: C5.1, IC2.1 (VOUT), RESET_BUTTON.3, RESET_BUTTON.4, R_RESET.2, U1.3 (EN)
RTC_RST: U1.16 (IO18), U3.4 (!RST)
RX: RX.TP, U1.24 (RXD0/GPIO17)
SCK: D8.2, J1.13, J4.P5 (CLK), R7.1, SCK.TP, U1.6 (IO6), U2.6 (CLK)
SCL: J3.4, R2_PINH.1, SENSOR2.4 (SCK), U1.20 (IO22), U3.16 (SCL), U4.7 (SCL)
SDA: J3.3, R1_PINH.1, SENSOR2.3 (SDI), U1.19 (IO21), U3.15 (SDA), U4.8 (SDA)
SRC: C4.2, D5.2 (A), L1.1, Q4.3 (D)
SS_SD: D11.2, J4.P2 (CD/DAT3), R10.1, U1.4 (IO4)
TX: TX.TP, U1.25 (TXD0/GPIO16)
USB_D+: D1.4 (I/O2_2), U1.14 (IO13)
USB_D-: D1.6 (I/O1_2), U1.13 (IO12)
VBAT: C2_BAT.1, MCP73831.3 (VBAT), Q1.3 (D), U4.2 (CELL), U4.3 (VDD), VBAT.TP
VBUS: C1_BAT.1, C4_USB.1, C5_USB.1, CHG_LED.A, D1.2 (GND), D2.2 (ANODE), MCP73831.4 (VIN), PFMF.050.1.2, Q1.1 (G), R1_PWRUSB.2, VBUS.TP
VRTC: C1.1, C10_SUPERCAP.1, R_CAPACITOR.2, U3.14 (VBAT)
VUSB: J2.A4, J2.A9, J2.B4, J2.B9, PFMF.050.1.1

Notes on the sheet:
USB C connector & ESD protection
LDO Voltage Regulator
SD Card
ESP32 C6
LI-Po Battery Charging Controller
E-Paper Drive Circuit
Display Type Selector
E-Paper Display Header
EPD Power
Environmental Sensor BME688
Voltage Supervisor + Reset &
Boot / IO Button
Battery ChargeLevel
RTC Module DS3231SN
Test Pads
Qwiic / Stemma QT
SPI ESD Protection Lines
External NORFlash64MB
drawn by: Aldobritei Catalin

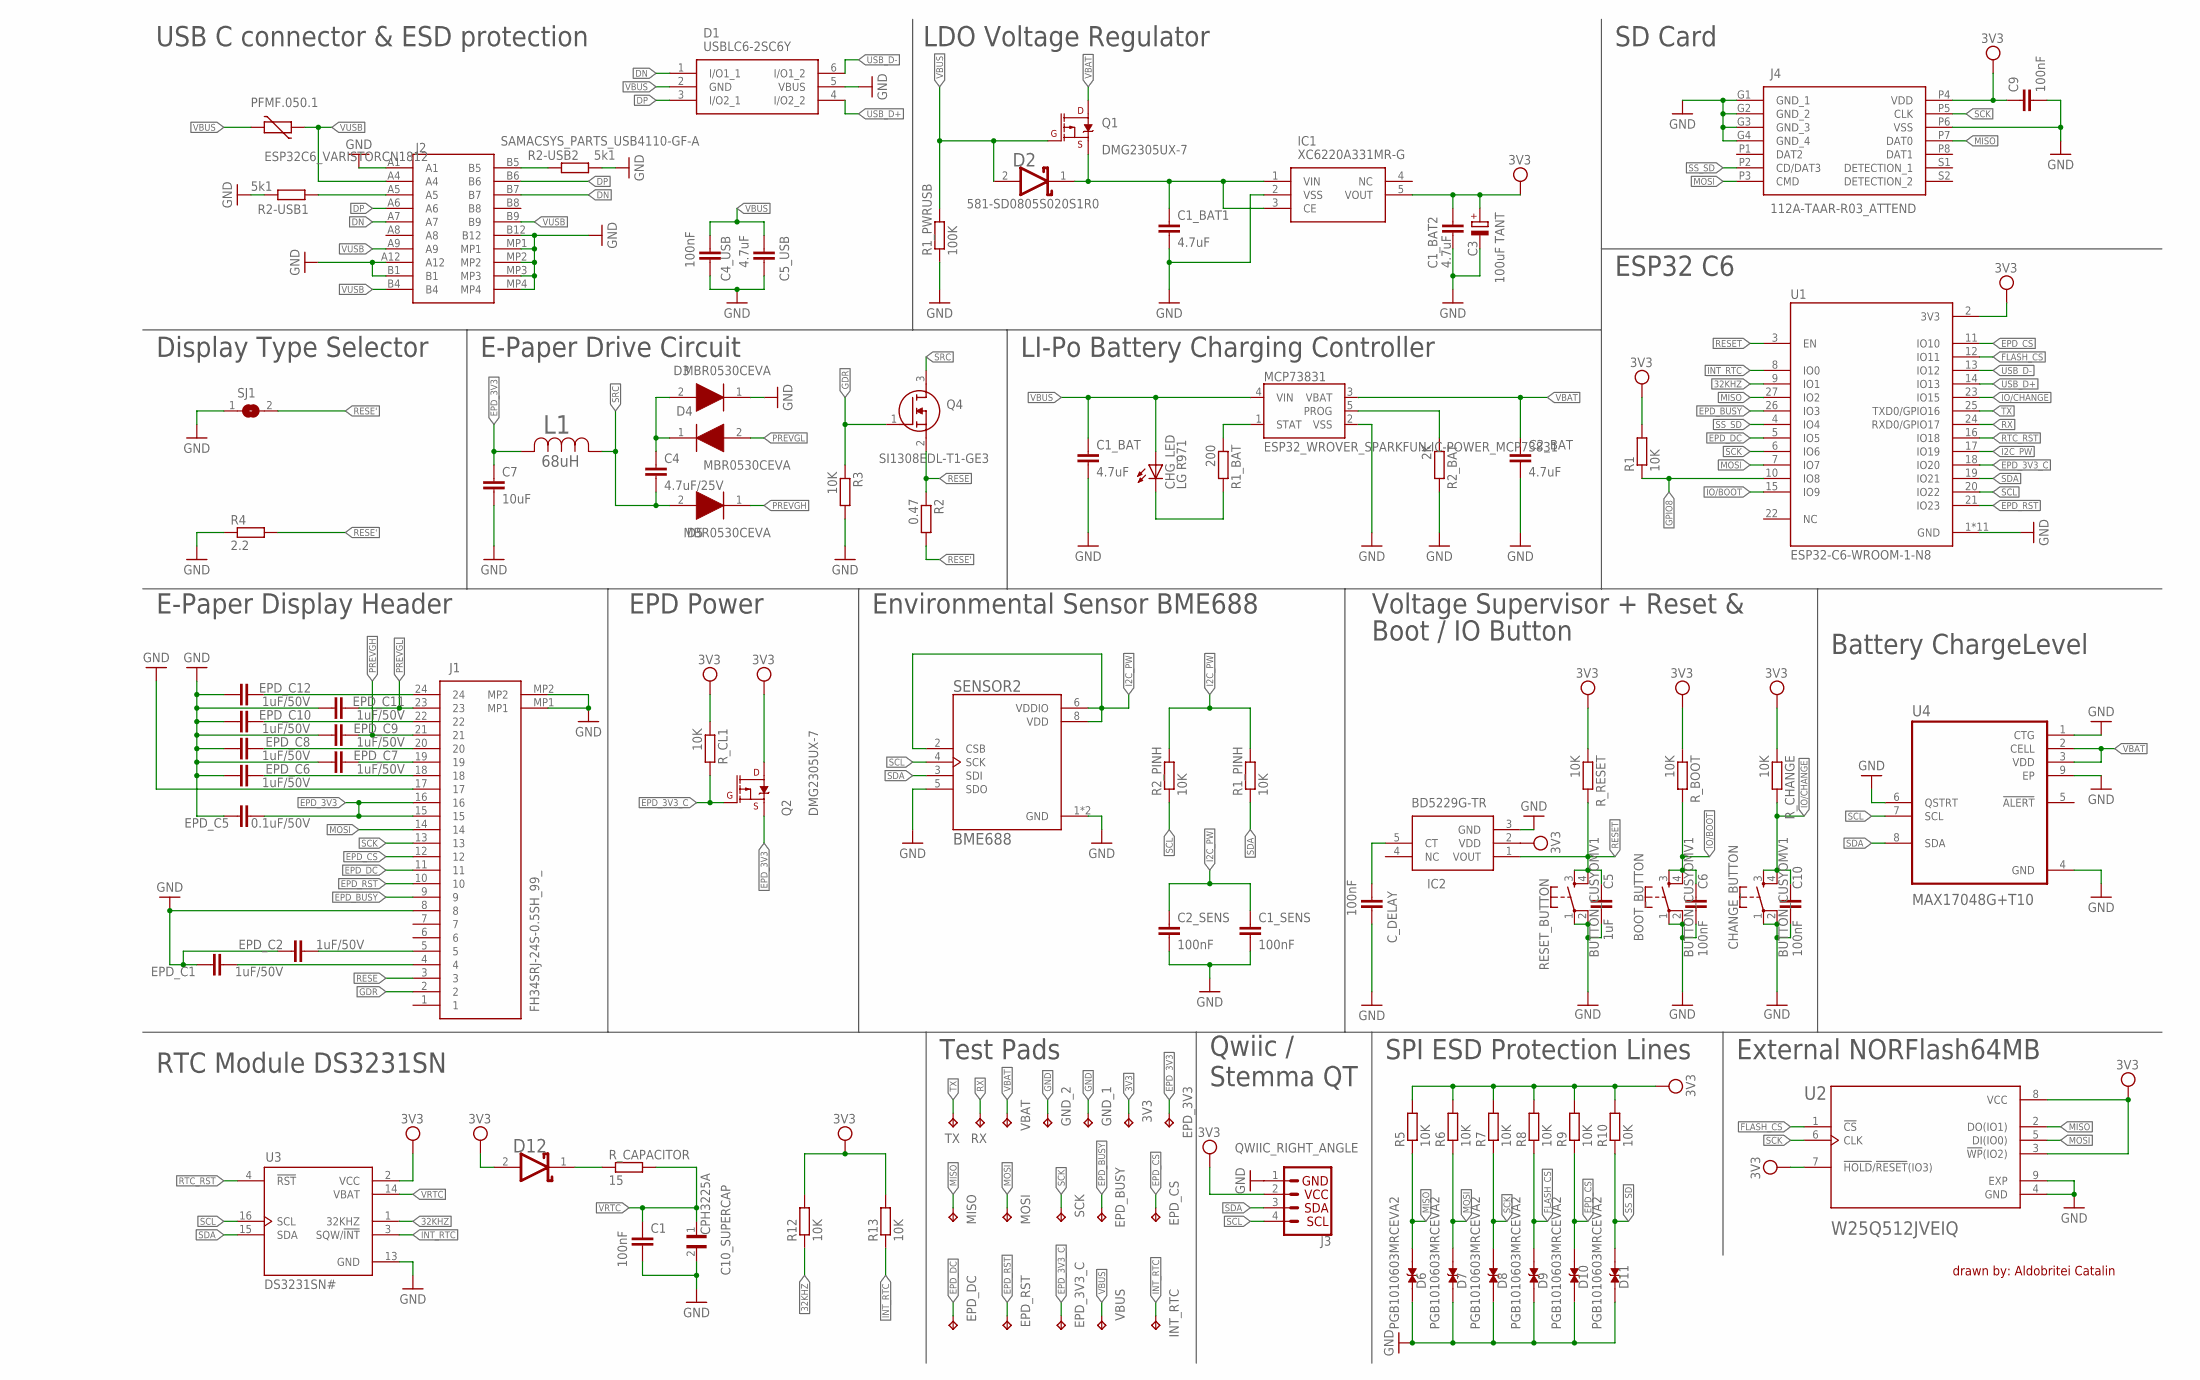
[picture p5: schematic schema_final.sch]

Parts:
3V3: TP; TP20R
BOOT_BUTTON: BUTTON_CUSYOMV1; MYBUTTON
C1, C1_SENS, C2_SENS, C4_USB, C6, C9, C10: 100nF; EAGLE-LTSPICE_C0402
C1_BAT, C1_BAT1, C1_BAT2, C2_BAT, C5_USB: 4.7uF; EAGLE-LTSPICE_C0402
C3: 100uF TANT; RCL_CT3528
C4: 4.7uF/25V; EAGLE-LTSPICE_C0402
C5: 1uF; EAGLE-LTSPICE_C0402
C7: 10uF; EAGLE-LTSPICE_C0402
C10_SUPERCAP: CPH3225A; CAPCP3225X100N
CHANGE_BUTTON: BUTTON_CUSYOMV1; MYBUTTON
CHG_LED: LG R971; ADAFRUIT_CHIP-LED0603
C_DELAY: 100nF; EAGLE-LTSPICE_C0402
D1: USBLC6-2SC6Y; SOT95P280X145-6N
D2, D12: ESP32_WROVER_AVX---SD0805S020S1R0_AVX_SD0805S020S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; ESP32_WROVER_AVX---SD0805S020S1R0_AVX_SD0805S020S1R0_0
D3, D4, D5: MBR0530CEVA; SOD3716X135N
D6, D7, D8, D9, D10, D11: PGB1010603MRCEVA2; DIOC1608X36N
EPD_3V3, EPD_3V3_C: TP; TP20R
EPD_BUSY: TP; TP20R
EPD_C1, EPD_C2, EPD_C6, EPD_C7, EPD_C8, EPD_C9, EPD_C10, EPD_C11, EPD_C12: 1uF/50V; EAGLE-LTSPICE_C0402
EPD_C5: 0.1uF/50V; EAGLE-LTSPICE_C0402
EPD_CS: TP; TP20R
EPD_DC: TP; TP20R
EPD_RST: TP; TP20R
GND_1, GND_2: TP; TP20R
IC1: XC6220A331MR-G; SOT95P280X120-5N
IC2: BD5229G-TR; SOT95P280X125-5N
INT_RTC: TP; TP20R
J1: FH34SRJ-24S-0.5SH_99_; FH34SRJ24S05SH99
J2: SAMACSYS_PARTS_USB4110-GF-A; SAMACSYS_PARTS_USB4110GFA
J3: QWIIC_RIGHT_ANGLE; JST04_1MM_RA
J4: 112A-TAAR-R03_ATTEND; 112ATAARR03ATTEND
L1: 68uH; IND_4828-WE-TPC_WRE
MCP73831: ESP32_WROVER_SPARKFUN-IC-POWER_MCP73831; ESP32_WROVER_SPARKFUN-IC-POWER_SOT23-5
MISO: TP; TP20R
MOSI: TP; TP20R
PFMF.050.1: ESP32C6_VARISTORCN1812; ESP32C6_VARISTOR_CT/CN1812
Q1, Q2: 20V/4.2A/52mΩ/1.4W; ESP32_WROVER_SPARKFUN-DISCRETESEMI_SOT23-3
Q4: SI1308EDL-T1-GE3; SOT65P210X110-3N
R1, R1_PINH, R2_PINH, R3, R5, R6, R7, R8, R9, R10, R12, R13: 10K; ESP32_WROVER_EAGLE-LTSPICE_R0402
R1_BAT: 200; ESP32_WROVER_EAGLE-LTSPICE_R0402
R1_PWRUSB: 100K; ESP32_WROVER_EAGLE-LTSPICE_R0402
R2: 0.47; ESP32_WROVER_EAGLE-LTSPICE_R0402
R2-USB1, R2-USB2: 5k1; ESP32_WROVER_EAGLE-LTSPICE_R0402
R2_BAT: 2K; ESP32_WROVER_EAGLE-LTSPICE_R0402
R4: 2.2; ESP32_WROVER_EAGLE-LTSPICE_R0402
RESET_BUTTON: BUTTON_CUSYOMV1; MYBUTTON
RX: TP; TP20R
R_BOOT: 10K; ESP32_WROVER_EAGLE-LTSPICE_R0402
R_CAPACITOR: 15; ESP32_WROVER_EAGLE-LTSPICE_R0402
R_CHANGE: 10K; ESP32_WROVER_EAGLE-LTSPICE_R0402
R_CL1: 10K; ESP32_WROVER_EAGLE-LTSPICE_R0402
R_RESET: 10K; ESP32_WROVER_EAGLE-LTSPICE_R0402
SCK: TP; TP20R
SENSOR2: BME688; ESP32_WROVER_BME680_PSON80P300X300X100-8N
SJ1: SJ
TX: TP; TP20R
U1: ESP32-C6-WROOM-1-N8; XCVR_ESP32-C6-WROOM-1-N8
U2: W25Q512JVEIQ; SON127P600X800X80-9N
U3: DS3231SN#; SOIC127P1032X265-16N
U4: MAX17048G+T10; SON50P200X200X80-9N
VBAT: TP; TP20R
VBUS: TP; TP20R

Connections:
3V3: 3V3.TP, C1_BAT2.2, C3.+, C9.1, D12.2 (ANODE), IC1.5 (VOUT), IC2.2 (VDD), J3.2, J4.P4 (VDD), Q2.3 (D), R1.2, R5.2, R6.2, R7.2, R8.2, R9.2, R10.2, R12.2, R13.2, R_BOOT.1, R_CHANGE.1, R_CL1.1, R_RESET.1, U1.2 (3V3), U2.3 (!WP!(IO2)), U2.7 (!HOLD!/!RESET!(IO3)), U2.8 (VCC), U3.2 (VCC)
32KHZ: R12.1, U1.9 (IO1), U3.1 (32KHZ)
DN: D1.1 (I/O1_1), J2.A7, J2.B7
DP: D1.3 (I/O2_1), J2.A6, J2.B6
EPD_3V3: C7.1, EPD_3V3.TP, EPD_C5.2, J1.15, J1.16, L1.2, Q2.2 (S)
EPD_3V3_C: EPD_3V3_C.TP, Q2.1 (G), R_CL1.2, U1.18 (IO20)
EPD_BUSY: EPD_BUSY.TP, J1.9, U1.26 (IO3)
EPD_CS: D10.2, EPD_CS.TP, J1.12, R9.1, U1.11 (IO10)
EPD_DC: EPD_DC.TP, J1.11, U1.5 (IO5)
EPD_RST: EPD_RST.TP, J1.10, U1.21 (IO23)
FLASH_CS: D9.2, R8.1, U1.12 (IO11), U2.1 (!CS)
GDR: J1.2, Q4.1 (G), R3.1
GND: BOOT_BUTTON.1, BOOT_BUTTON.2, C1.2, C1_BAT.2, C1_BAT1.2, C1_BAT2.1, C1_SENS.2, C2_BAT.2, C2_SENS.2, C3.-, C4_USB.2, C5.2, C5_USB.2, C6.2, C7.2, C9.2, C10.2, C10_SUPERCAP.2, CHANGE_BUTTON.1, CHANGE_BUTTON.2, C_DELAY.2, D1.5 (VBUS), D3.1 (K), D6.1, D7.1, D8.1, D9.1, D10.1, D11.1, EPD_C1.1, EPD_C2.1, EPD_C5.1, EPD_C6.1, EPD_C7.1, EPD_C8.1, EPD_C9.1, EPD_C10.1, EPD_C11.1, EPD_C12.1, GND_1.TP, GND_2.TP, IC1.2 (VSS), IC2.3 (GND), J1.8, J1.17, J1.MP1, J1.MP2, J2.A1, J2.A12, J2.B1, J2.B12, J2.MP1, J2.MP2, J2.MP3, J2.MP4, J3.1, J4.G1 (GND_1), J4.G2 (GND_2), J4.G3 (GND_3), J4.G4 (GND_4), J4.P6 (VSS), MCP73831.2 (VSS), R1_PWRUSB.1, R2-USB1.1, R2-USB2.2, R2_BAT.2, R3.2, R4.1, RESET_BUTTON.1, RESET_BUTTON.2, SENSOR2.1 (GND), SENSOR2.5 (SDO), SENSOR2.7 (GND), SJ1.1, U1.1 (GND), U1.28 (GND), U1.29_1 (GND), U1.29_2 (GND), U1.29_3 (GND), U1.29_4 (GND), U1.29_5 (GND), U1.29_6 (GND), U1.29_7 (GND), U1.29_8 (GND), U1.29_9 (GND), U2.4 (GND), U2.9 (EXP), U3.13 (GND), U4.1 (CTG), U4.4 (GND), U4.6 (QSTRT), U4.9 (EP)
GND1: J2.B5, R2-USB2.1
GPIO8: R1.1, U1.10 (IO8)
INT_RTC: INT_RTC.TP, R13.1, U1.8 (IO0), U3.3 (SQW/!INT)
IO/BOOT: BOOT_BUTTON.3, BOOT_BUTTON.4, C6.1, R_BOOT.2, U1.15 (IO9)
IO/CHANGE: C10.1, CHANGE_BUTTON.3, CHANGE_BUTTON.4, R_CHANGE.2, U1.23 (IO15)
MISO: D6.2, J4.P7 (DAT0), MISO.TP, R5.1, U1.27 (IO2), U2.2 (DO(IO1))
MOSI: D7.2, J1.14, J4.P3 (CMD), MOSI.TP, R6.1, U1.7 (IO7), U2.5 (DI(IO0))
unnamed: J2.A5, R2-USB1.2
unnamed: EPD_C7.2, J1.19
unnamed: MCP73831.1 (STAT), R1_BAT.1
unnamed: C1_BAT1.1, D2.1 (CATHODE), IC1.1 (VIN), IC1.3 (CE), Q1.2 (S)
unnamed: CHG_LED.C, R1_BAT.2
unnamed: EPD_C6.2, J1.18
unnamed: MCP73831.5 (PROG), R2_BAT.1
unnamed: C4.1, D3.2 (A), D4.1 (K)
unnamed: EPD_C8.2, J1.20
unnamed: EPD_C10.2, J1.22
unnamed: EPD_C12.2, J1.24
unnamed: C_DELAY.1, IC2.5 (CT)
unnamed: EPD_C2.2, J1.5
unnamed: EPD_C1.2, J1.4
unnamed: D12.1 (CATHODE), R_CAPACITOR.1
PREVGH: D5.1 (K), EPD_C9.2, J1.21
PREVGL: D4.2 (A), EPD_C11.2, J1.23
RESE: J1.3, Q4.2 (S), R2.1
RESE': R2.2, R4.2, SJ1.2
RESET: C5.1, IC2.1 (VOUT), RESET_BUTTON.3, RESET_BUTTON.4, R_RESET.2, U1.3 (EN)
RTC_RST: U1.16 (IO18), U3.4 (!RST)
RX: RX.TP, U1.24 (RXD0/GPIO17)
SCK: D8.2, J1.13, J4.P5 (CLK), R7.1, SCK.TP, U1.6 (IO6), U2.6 (CLK)
SCL: J3.4, R2_PINH.1, SENSOR2.4 (SCK), U1.20 (IO22), U3.16 (SCL), U4.7 (SCL)
SDA: J3.3, R1_PINH.1, SENSOR2.3 (SDI), U1.19 (IO21), U3.15 (SDA), U4.8 (SDA)
SRC: C4.2, D5.2 (A), L1.1, Q4.3 (D)
SS_SD: D11.2, J4.P2 (CD/DAT3), R10.1, U1.4 (IO4)
TX: TX.TP, U1.25 (TXD0/GPIO16)
USB_D+: D1.4 (I/O2_2), U1.14 (IO13)
USB_D-: D1.6 (I/O1_2), U1.13 (IO12)
VBAT: C2_BAT.1, MCP73831.3 (VBAT), Q1.3 (D), U4.2 (CELL), U4.3 (VDD), VBAT.TP
VBUS: C1_BAT.1, C4_USB.1, C5_USB.1, CHG_LED.A, D1.2 (GND), D2.2 (ANODE), MCP73831.4 (VIN), PFMF.050.1.2, Q1.1 (G), R1_PWRUSB.2, VBUS.TP
VRTC: C1.1, C10_SUPERCAP.1, R_CAPACITOR.2, U3.14 (VBAT)
VUSB: J2.A4, J2.A9, J2.B4, J2.B9, PFMF.050.1.1

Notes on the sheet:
USB C connector & ESD protection
LDO Voltage Regulator
SD Card
ESP32 C6
LI-Po Battery Charging Controller
E-Paper Drive Circuit
Display Type Selector
E-Paper Display Header
EPD Power
Environmental Sensor BME688
Voltage Supervisor + Reset &
Boot / IO Button
Battery ChargeLevel
RTC Module DS3231SN
Test Pads
Qwiic / Stemma QT
SPI ESD Protection Lines
External NORFlash64MB
drawn by: Aldobritei Catalin

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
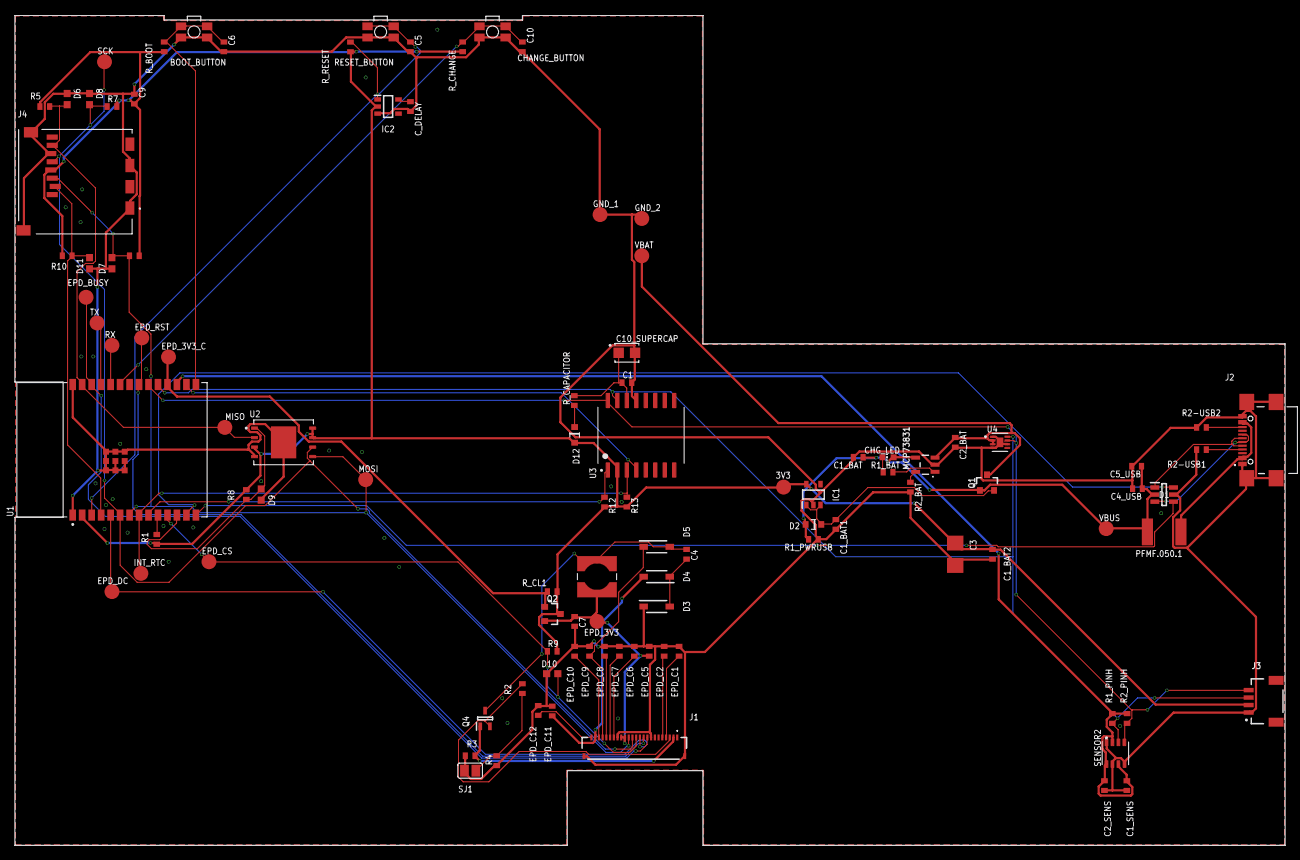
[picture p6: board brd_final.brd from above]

Board: 2 copper layers, 170.2 x 111.2 mm, 103 parts (0 on the bottom side), 55 nets.

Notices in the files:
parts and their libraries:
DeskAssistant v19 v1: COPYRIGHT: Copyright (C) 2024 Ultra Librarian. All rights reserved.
